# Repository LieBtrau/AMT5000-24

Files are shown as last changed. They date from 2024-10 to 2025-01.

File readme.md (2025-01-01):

# AMT5000-24
5W AM-transmitter for the 13.56MHz ISM-band

# Design choice
* DfM (Design for Manufacturability)
  * Use of COTS components
  * Use of standard PCB manufacturing techniques, no coil winding
  * Use of standard assembly techniques, preferably SMT
  * Ease of patching : SOIC instead of TSSOP
* Frequency : 13.56 MHz
  * ISM-band
  * Falls within SW-broadcast band, so AM-radios can be used
  * Antenna-length for a dipole is reasonable
  * [Carrier current](https://en.wikipedia.org/wiki/Carrier_current) is possible.  The mains power impedance isn't too low at this frequency.
  * 13.56MHz Class-E power amplifier designs is not uncommon
* Output power : 5W
  * remains within QRP limits

# Block diagram
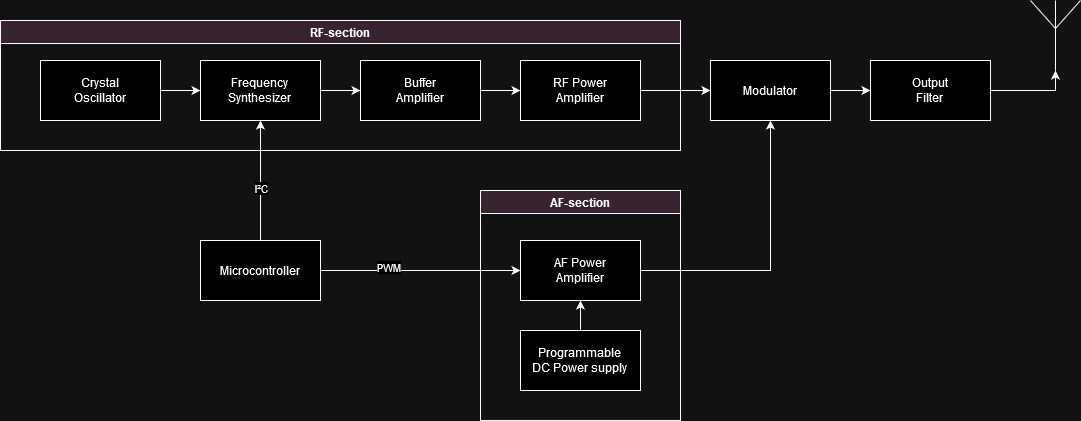
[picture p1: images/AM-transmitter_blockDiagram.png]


High-level AM-generator block diagram

## RF-section (Radio-frequency)
* [Crystal Oscillator & frequency synthesizer](./oscillator.md)
* [Buffer amplifier & RF-power amplifier](./rf-amp.ipynb)

## AF-section (Audio-frequency)
* Audio PWM-modulator using H-bridge IC (as on TR6000) : CSD97395Q4M
* [PWM-generator by ESP32 output](https://docs.espressif.com/projects/esp-iot-solution/en/latest/audio/pwm_audio.html)

## Modulator
Modulation happens by the output of the PWM-generator being used as power supply for the RF-power amplifier.

## Output filter
The output filter suppresses the harmonics of the switching frequency of the RF-power amplifier.

# Implementation
Instead of building a complete transmitter at once.  Prototyping will be done in stages.  The sections mentioned above will be designed as 50x50mm PCBs.  These will be tested separately and then combined onto a double sided 100x100mm FR4.  This allows us to:
* Test the sections separately and in combination with each other.
* A cheap double sided FR4 PCB can be used as a carrier for the sections.  This allows us to test the sections in combination with each other.
* Use the cheap PCB manufacturing services, like JLCPCB.  The 6 layer 50x50mm PCBs are only $2/5pcs.
* JST-PH will be used as connectors between the sections.
  * JST-PH for power
  * JST-PH for signals

The disadvantage is that the sections will be connected by wires, but we can use u.fl coax cables for signals.  All components should be SMD, not through hole, because of the carrier PCB.

# Why AM and not FM?
* Higher field strengths are allowed
* Receiver bandwidths are narrower (lower noise floor)
* AM is superior to FM under weak-signal conditions
* AM-band has more usable channels than FM
* construction is less critical because frequencies are low.
* only simple test equipment is needed

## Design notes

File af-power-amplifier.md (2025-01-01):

# Amplifier
There are three options to supply audio to the amplifier:
* Analog
  * Might suffer from noise, ground loops
  * Very versatile.  Allows to connect any audio source.
  * Simple software implementation, maybe even no software implementation at all.
* PWM
  * Fully digital signal path
  * CPU intensive, limited resolution and sampling rate
* I²S
  * Fully digital signal path
  * Less CPU intensive, higher resolution and sampling rate
  * An MCU with I²S output is needed

After much consideration, the analog input is chosen.

## Analog input
An alternative to generating audio by PWM is using a single ended class D amplifier with analog audio input.
Class-D amplifiers are much more efficient than class-AB amplifiers (e.g. the obsolete TDA2003).  The downside is that they're more complex.

### MPS options
The MP7740 and MP7741 are such devices.  They're not available on JLCPCB.
Their minimum input voltage is 9.5V, which is already quite high.  We might want to test the circuit with lower supply voltages to avoid burning the amplifier.

### TI options
[SLAA701A LC Filter Design](https://www.ti.com/lit/an/slaa701a/slaa701a.pdf) explains the difference between the BD-modulator and the AD-modulator.  Both modulators have a positive and Aan inverted output.  The difference is only in the inverted output.  For our application we can ignore the difference when using only the positive output.

Most recent class-D amplifiers use the BD-modulator.  The TPA3138D2 is such an amplifier.  It can be used as single ended, but TI [doesn't really recommend it](https://e2e.ti.com/support/audio-group/audio/f/audio-forum/927759/tpa3138d2-using-btl-amplifier-for-se-outputs-for-cost-savings). 
* TPA3118D2 (older) -> TPA3128D2 (upgrade): 2x 30W
    * JLCPCB

The following older class-D amplifiers use the AD-modulator:
* TPA3120D2
* TPA3121D2 (available on JLCPCB)
* TPA3123D2
* TPA3124D2 (compatible with the TPA3121D2, only a small difference in the mute control)

## PWM input
A fully digital signal path is used.  The ESP32 generates the PWM signal using the [PWM-audio component](https://docs.espressif.com/projects/esp-iot-solution/en/latest/audio/pwm_audio.html).  The PWM signal is fed to a half-bridge IC, which drives the speaker.

### Audio bandwidth
The minimum audio bandwidth for AM is around 3kHz.  The Qodosen DX-286 has a configurable audio bandwidth of 3kHz, 4kHz, 6kHz or even 8kHz.
So the minimum audio sampling rate should be at least 16kHz.

### PWM frequency & resolution
[PWM Distortion Analysis](http://www.openmusiclabs.com/learning/digital/pwm-dac/pwm-distortion-analysis/).  Key takeaways are :
* PWM is multiplication of your audio signal with a square wave at the PWM frequency
* Harmonics of the PWM frequency are generated
* Harmonics of the audio frequency are generated as well, because the audio signal isn't continuous, but a series of samples, sampled at the PWM frequency.
* Phase correct PWM has less (around 25dB) distortion than fast PWM
* PWM frequency should be at least 7 to 10 times the audio frequency

The ESP32 audio component only supports up to 48kHz PWM frequency, which is only three times the sampling frequency.

### Half-bridge IC
[CSD97395Q4M](https://www.ti.com/lit/ds/symlink/csd97395q4m.pdf)
* 60A peak current.  It's available on JLCPCB.
* The minimum ON-time is 40ns.
* €1.80 is quite expensive, but that's about the cheapest you can get for a half-bridge IC.

### Reconstruction filter


The PWM signal is fed to a low-pass filter to remove the PWM frequency and its harmonics.  The filter is a 2nd order Butterworth filter with a cutoff frequency of 6kHz, designed by [Markimicrowave](https://markimicrowave.com/technical-resources/tools/lc-filter-design-tool/).  The filter is designed for a 1ohm load impedance.
* L = 39µH → L = Wuerth 744776139 (lowest loss at 13.56MHz)
* C = 39µF → 4x 10µF, 1210 package

## I2S input
* TAS2770
  * minimum sampling rate is 44.1kHz.  48kHz is supported.
  * 20W output power
* TAS2505 has a class-D amplifier with I²S input. 
  * only 2W output power, so an extra half-bridge IC is needed.
  * Support for 8kHz to 96kHz sampling rates
  * available on JLCPCB (€1.50)
  * also has an analog input
  * the output pins don't seem to be perfectly differential according to the screenshots in the TI forum.
  * only 2W output power
* MAX98357A has a class-D amplifier with I²S input.  It's available on JLCPCB.
  * much more expensive than the TAS2505
  * simpler to use than the TAS2505
* PCM5242RHBR
  * used on Rapsberry Pi HATs
  * €9 @ JLCPCB (expensive!)

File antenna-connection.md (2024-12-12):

# RF-connector
* BNC : bulky, but easy to connect
* SMA : smaller but it takes some time to connect.  No visible check if it's connected properly.  You have to turn it to check it.
* U.FL : too small.  A cable assembly to a panel mount connector would be needed.  That introduces loss and extra cost.
* **MMCX** : a good compromise between BNC and SMA.  It's small and easy to connect.  It's also available in a panel mount version.  Popular in the drone industry.

# Protection
## Over-voltage
Over-voltage protection should be low capacitance but high voltage.  A GDT (gas discharge tube) seems like the only option here.

## Static discharge
The filter section of the class-E amplifier is isolated from ground.  To avoid building up a static charge, the filter section should be connected to ground.  This can be done with a 1M resistor.

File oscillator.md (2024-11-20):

# Oscillator
A crystal could be used, but we won't get better than 10ppm, let's use a TCXO instead.

## Requirements
* 25MHz or 27MHz
* sine wave output
* 3.3V supply
* Less than €2/pce
* frequency tolerance < 2ppm

## Part selection
SX2T25.000B010J020S

# Frequency synthesizer
The ESP32 can generate waveforms at 40MHz and much lower frequencies using the LEDC-peripheral, but the frequency resolution is very limited.  A PLL is required.  The Si5351A will be used:
* cheap
* popular in open-source projects, open-source code is available
* requires external crystal or clock

## Part selection
* Skyworks SI5351A-B-GTR, JLCPCB C504891
* MS5351M : less phase noise, but it's a clone.

# References
[QRP Labs Si5351A Synthesiser Module, PCB Rev 6](https://www.qrp-labs.com/images/synth/synth_assembly6.pdf)

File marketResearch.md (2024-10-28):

# Hobby circuits
* [How to Build an AM Radio Transmitter](https://www.circuitbasics.com/amplitude-modulated-transmitters/)
  * Colpitts oscillator in final stage.  Audio modulates the oscillator.
* [Build an AM Transmitter for Use with Antique Radios](https://www.nutsvolts.com/magazine/article/build-an-am-transmitter-for-use-with-antique-radios)
  * All linear circuits, no switching going on here.
* [M0DAD The Poppet](http://www.geocities.ws/raiu_harrison/mwa/tech/circuits/poppet.html)
  * Class-C amplifier
* [A simple AM modulator](https://www.giangrandi.org/electronics/am-mod/am-mod.shtml)
  * Class-C amplifier
* [FAT5 AM Transmitter](https://www.s9plus.com/index.html)
  * AM-transmitter in modules : Class E RF-amp, modulator (linear or PWM), oscillator

# Transmitter evaluation
## AM88
* Described in : "Build Your Own Low-Power Transmitters: Projects for the Electronics Experimenter by Rudolf F. Graf", §5. PLL Synthesized AM Transmitter for 530-1710 kHz
* 12VDC power supply
* AGC circuit
* PLL circuit could be replaced by MCU
* Chebychev output for filtering 2nd harmonic.  3 filters needed for 150kHz-1.8MHz range.

## DT6000
* [improved transmitter over AMT3000 and AMT5000](https://github.com/TransmitterPlans/DT6000-Transmitter-Files-)
  * [SSTRAN AMT-3000 am transmitter](http://www.radiomanual.info/schemi/Surplus_Radioamateur/SStran_AMT-3000_user.pdf)
  * [SSTRAN AMT-5000 ](https://github.com/TransmitterPlans/DT6000-Transmitter-Files-/blob/main/340473333-AMT5000Manual-R1-20110918-1106PM.pdf)
* Schematic is hard to read.
* includes antenna building info in appendix
* Uses AMT3000 audio / RF sections 
* 100mW
* AD9833 : DDS square wave generator
* ATMega328 control

## Wenzel
* [AM-transmitter](https://techlib.com/electronics/amxmit.htm)
* Low Power
* Also contains antenna tuning info
* LPAM handbook (includes antenna building info)

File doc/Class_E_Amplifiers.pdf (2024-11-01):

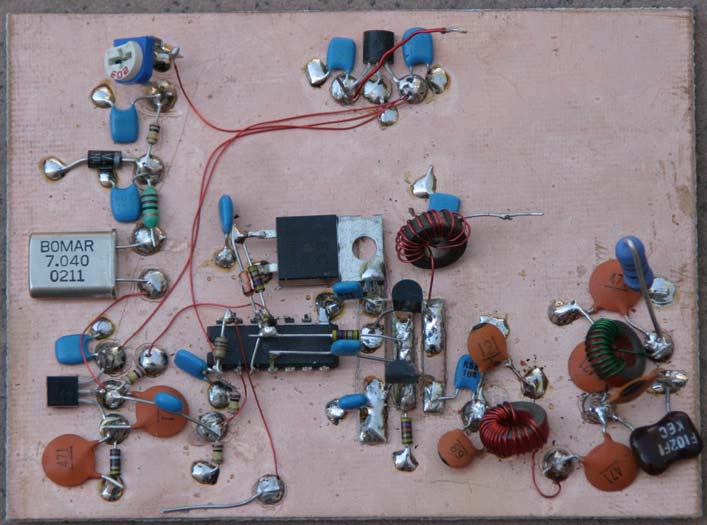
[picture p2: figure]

April-04 | N7VE / Ozarkc Copyright 1994, All rights reserved | on Class E Presentation

# Class E Amplifiers

## Part 1: Class E Basics

## Dan Tayloe, N7VE

## 5w Class E 40m Prototype

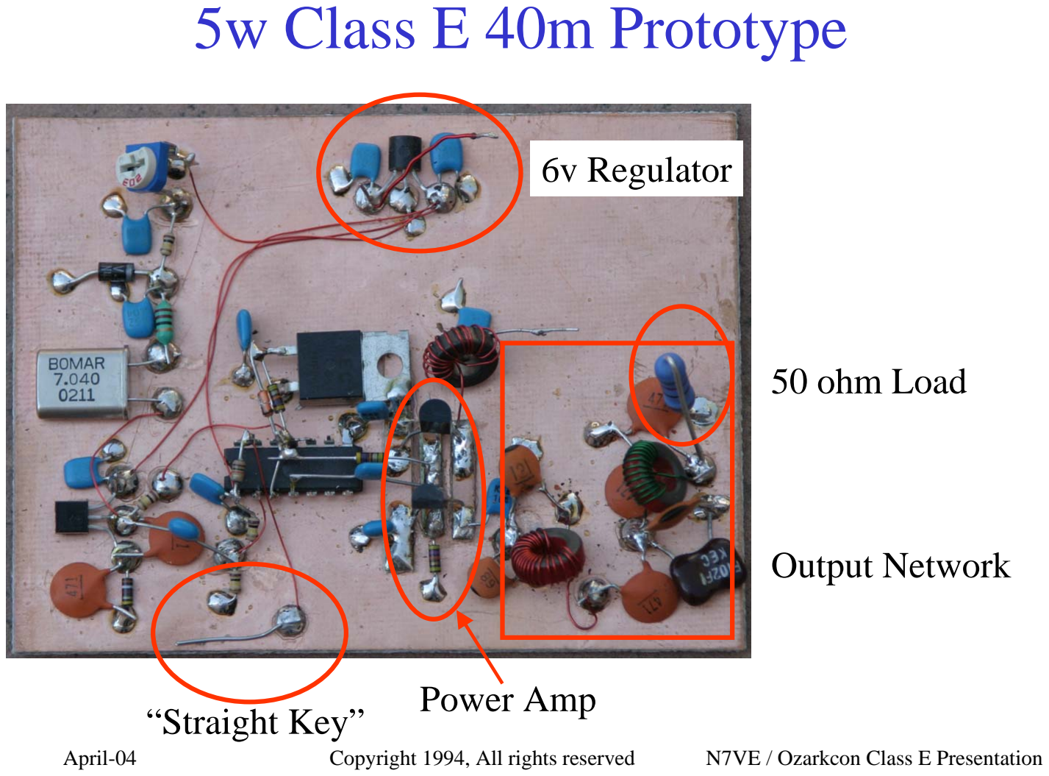
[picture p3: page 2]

April-04 | N7VE / Ozarkc Copyright 1994, All rights reserved | on Class E Presentation

Power Amp

6v Regulator

Output Network

50 ohm Load

“Straight Key”

April-04 | N7VE / Ozarkc Copyright 1994, All rights reserved | on Class E Presentation

# Why Class E?

Class C final, 2w
40 to 45% efficient, ~ 370 to 410 ma*

Class E final, 2w
88% efficient, ~ 190 ma*

Almost 50% less TX current required… Very battery friendly!

* Does not include PA driver. Class E can require very little driver power!

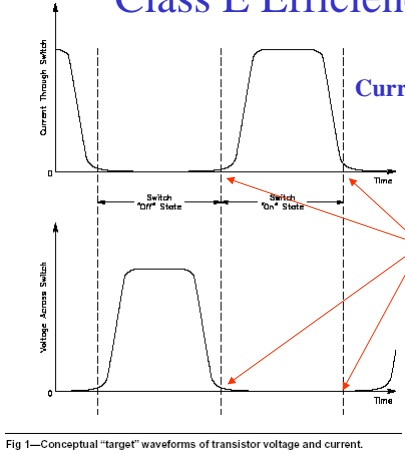
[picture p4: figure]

April-04 | N7VE / Ozarkc Copyright 1994, All rights reserved | on Class E Presentation

# Class E Efficiency Secret

Voltage vs. time

Current vs. time

Taken from QEX Jan/Feb 2001

Switch at low current,
Low voltage points
~Zero power at switch!

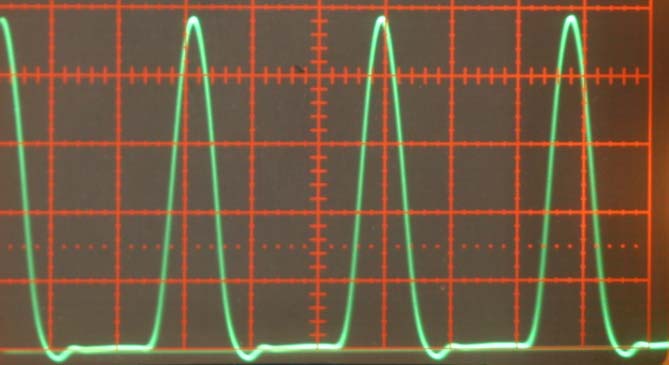
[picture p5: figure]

April-04 | N7VE / Ozarkc Copyright 1994, All rights reserved | on Class E Presentation

# Class E Drain Voltage Waveform

Scale 10v/division
~ 48v at peaks for 5 w, ~40v for 2w
For comparison, Class C devices run only 24v peaks

## Class E Design Spread Sheet, 7 MHz

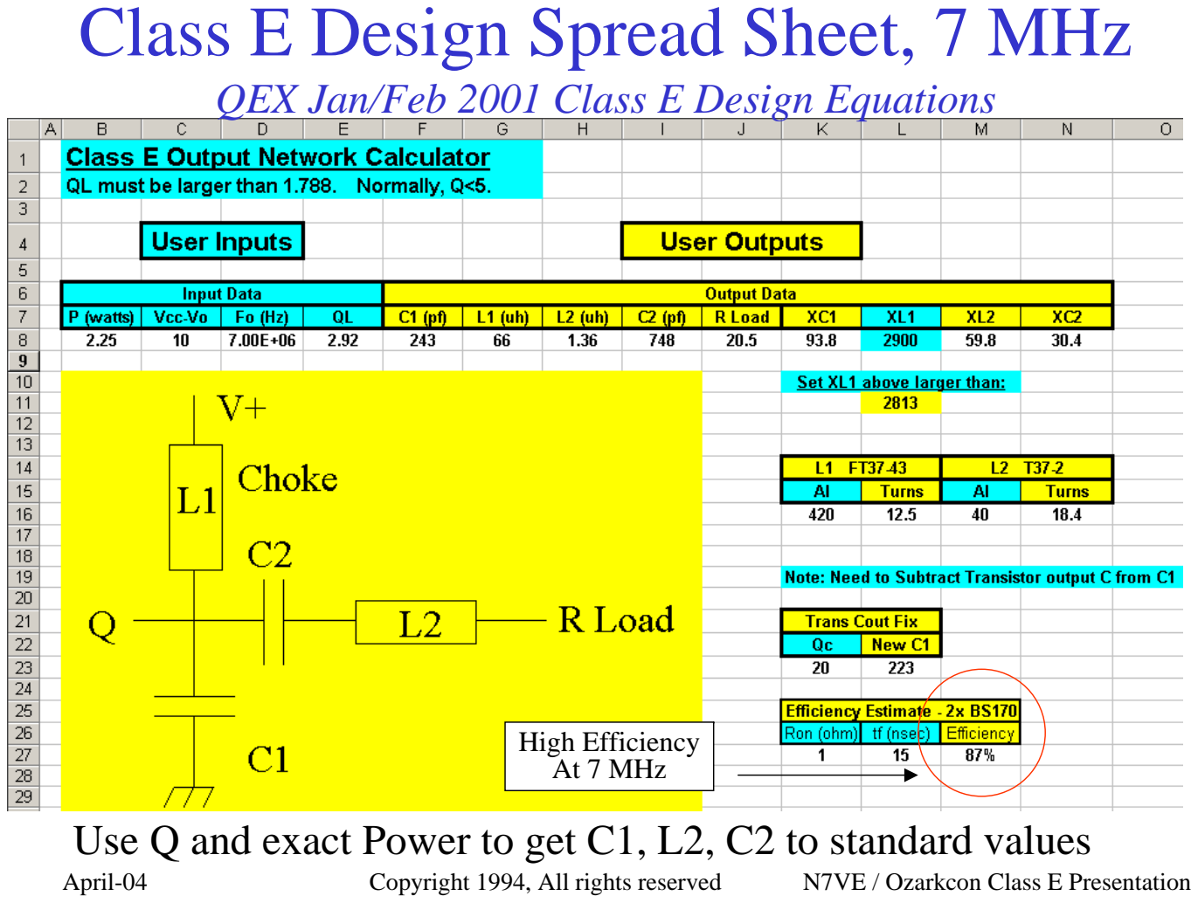
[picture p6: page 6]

April-04 | N7VE / Ozarkc Copyright 1994, All rights reserved | on Class E Presentation

QEX Jan/Feb 2001 Class E Design Equations

High Efficiency
At 7 MHz
Use Q and exact Power to get C1, L2, C2 to standard values

## Class E Design Spread Sheet, 14 MHz

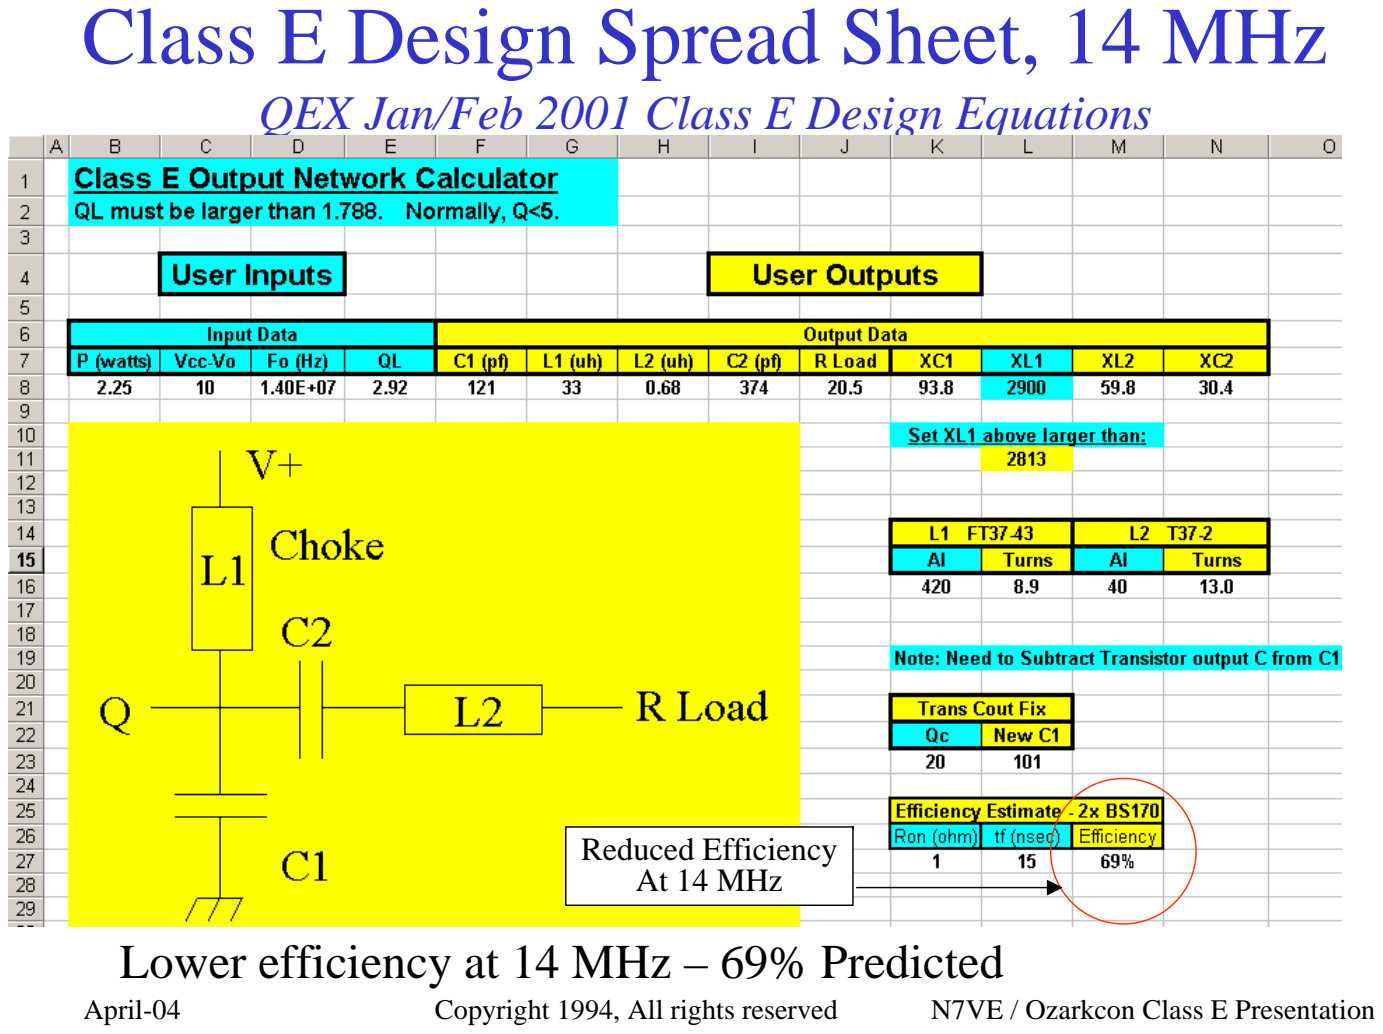
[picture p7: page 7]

April-04 | N7VE / Ozarkc Copyright 1994, All rights reserved | on Class E Presentation

QEX Jan/Feb 2001 Class E Design Equations

Reduced Efficiency
At 14 MHz
Lower efficiency at 14 MHz – 69% Predicted

April-04 | N7VE / Ozarkc Copyright 1994, All rights reserved | on Class E Presentation

# Class E Design Spread Sheet

Excel spread sheet equations…

C1 (pf) = (1e12/(J8*34.2219*D8))*(0.99866 + 0.91424/(E8) -1.03175/(E8*E8)) + 0.6/(2*2*3.14*3.14*D8*D8*G8/1000000)

C2 (pf) = (1e12/(J8*2*3.14*D8))*(1/(E8-0.104823)) *(1.00121 + 1.01468/(E8 - 1.7879)) -0.2/(2*2*3.14*3.14*D8*D8*G8/1000000)

L1 (uH) = 1000000*L8/(2*3.14*D8)

L2 (uH) = 1000000*J8*E8/(2*3.14*D8)

Rload = (C8*C8/B8)*0.576801*(1.001245 - 0.451759/E8 - 0.402444/(E8*E8))

XL1 >= 30*K8

Efficiency = J8/(J8+1.365*K27) -0.01
- (1+ 0.82/E8)* (1+ 0.82/E8)*4*PI()*PI()*D8*D8*L27*L27*1e-18/12

April-04 | N7VE / Ozarkc Copyright 1994, All rights reserved | on Class E Presentation

# Class E Amplifiers

## Part 2: No Tune, Goof Proof Class E Amps

## Dan Tayloe, N7VE

April-04 | N7VE / Ozarkc Copyright 1994, All rights reserved | on Class E Presentation

# Problems with Class E QRP Amps

- “Tuning” required to get good efficiency
- Poor “out of the box” power and efficency
- Typical to “tweak” output network coils for best power/efficiency
- Class E finals fail when presented with low impedance loads
- Low impedance loads cause PA to draw too much current and burn up
- Inexpensive QRP Class E final rated to only 60v (2N7000)
- Typical PA drain voltage operates in the 40 to 50v range w/ 12v supply
- Improper antenna mismatch can raise drain voltage, blow the PA
- 15v supply used with a 12v design could cause problems
- Class E Amps can be unstable into poorly matched loads
- Tends to “take off”
- Can lead to device failure

April-04 | N7VE / Ozarkc Copyright 1994, All rights reserved | on Class E Presentation

# Class E Tuning Problem

- Class E matching network typically presents a reactive load
- I.e., the Class E PA output impedance is not purely resistive
- Reactive characteristic key to Class E efficiency
- QRP Class E networks need loads in the 10 ohm to 50 ohm (5w to 1w) range
- Matching network normally needed to transform to 50 ohm load
- 1 watt 12v final is a design “sweet spot” – no matching needed
- L/C matching networks are typically used to transform driver impedance to 50 ohm load impedance.
- This approach does not work well with a reactive drive source!
- Leads to frequency specific matching network
- Variations in driver network and matching network elements force the need for “tuning” of the matching networks

# No Tune Class E

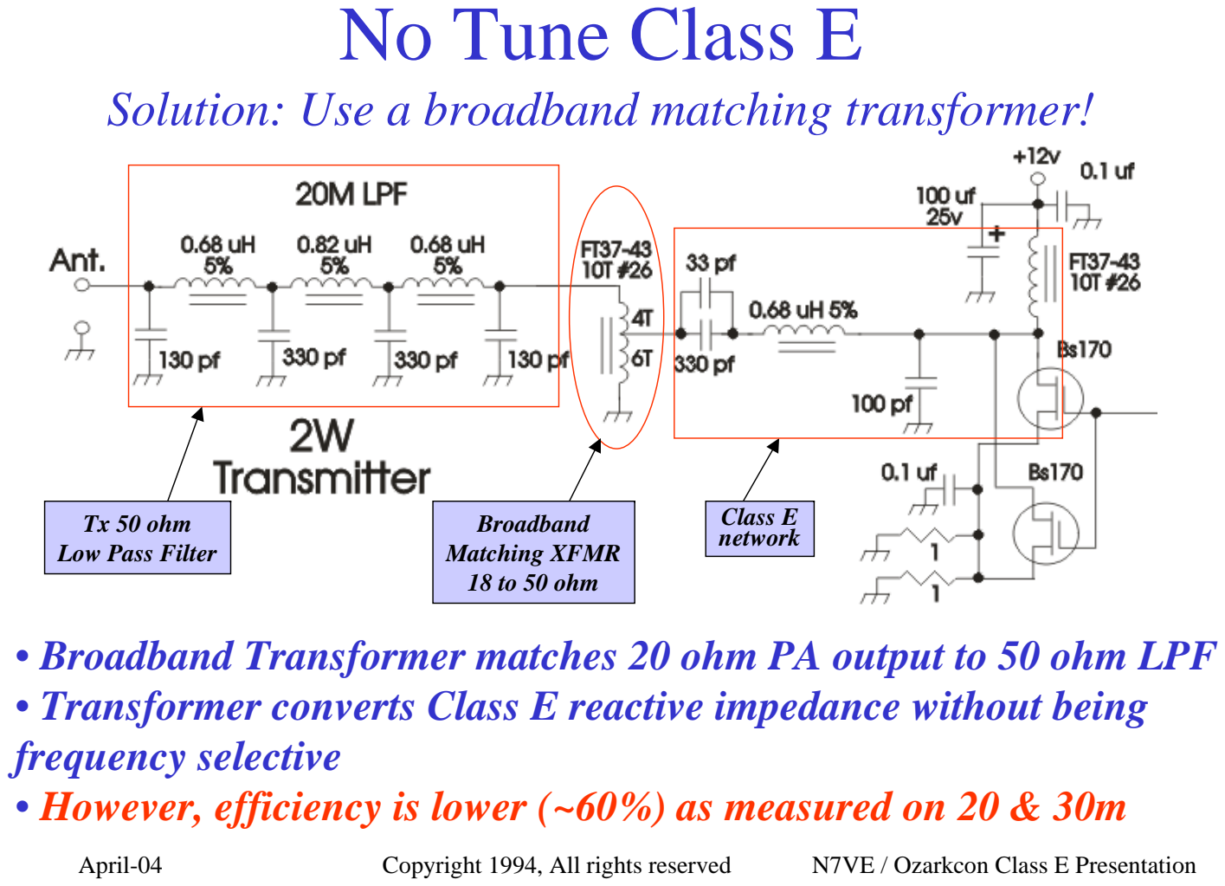
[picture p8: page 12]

April-04 | N7VE / Ozarkc Copyright 1994, All rights reserved | on Class E Presentation

Solution: Use a broadband matching transformer!

- Broadband Transformer matches 20 ohm PA output to 50 ohm LPF
- Transformer converts Class E reactive impedance without being frequency selective
- However, efficiency is lower (~60%) as measured on 20 & 30m

Tx 50 ohm
Low Pass Filter

Broadband
Matching XFMR

### 18 to 50 ohm

Class E
network

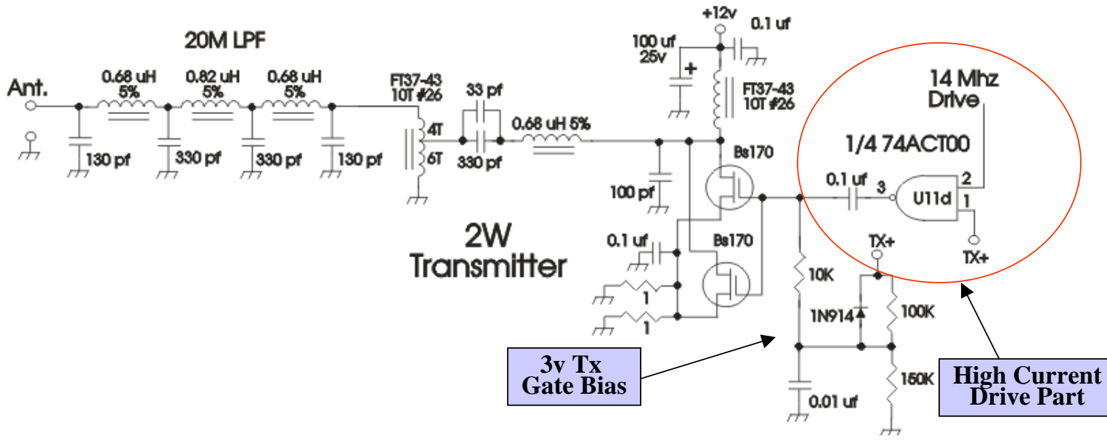
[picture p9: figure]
Gate Bias; High Current Drive Part

April-04 | N7VE / Ozarkc Copyright 1994, All rights reserved | on Class E Presentation

# Class E Load Instability

Solution: Use a lower impedance gate driver!

- AC family has 24 ma of drive vs 8 ma for HC family
- Higher current drive = lower drive source impedance
- 3x lower source impedance reduces tendency to “flight” with mismatched load
- PA gate biased on TX to 3v to help MOSFET turn on harder

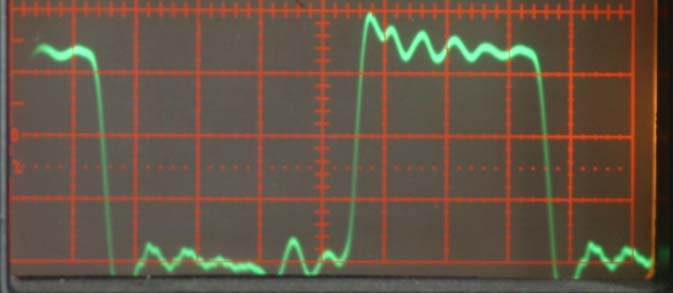
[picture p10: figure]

April-04 | N7VE / Ozarkc Copyright 1994, All rights reserved | on Class E Presentation

# Class E Driver – 74ACT00

Scale: Vertical 2v/div, Horizontal 20 nsec/div 6 to 8v at peaks
Very fast rise+fall times: ~10 nsec total

74ACT00 has 24 ma of drive vs. only

8 ma for
the more common 74HCT00 parts

# Class E Voltage Limitations

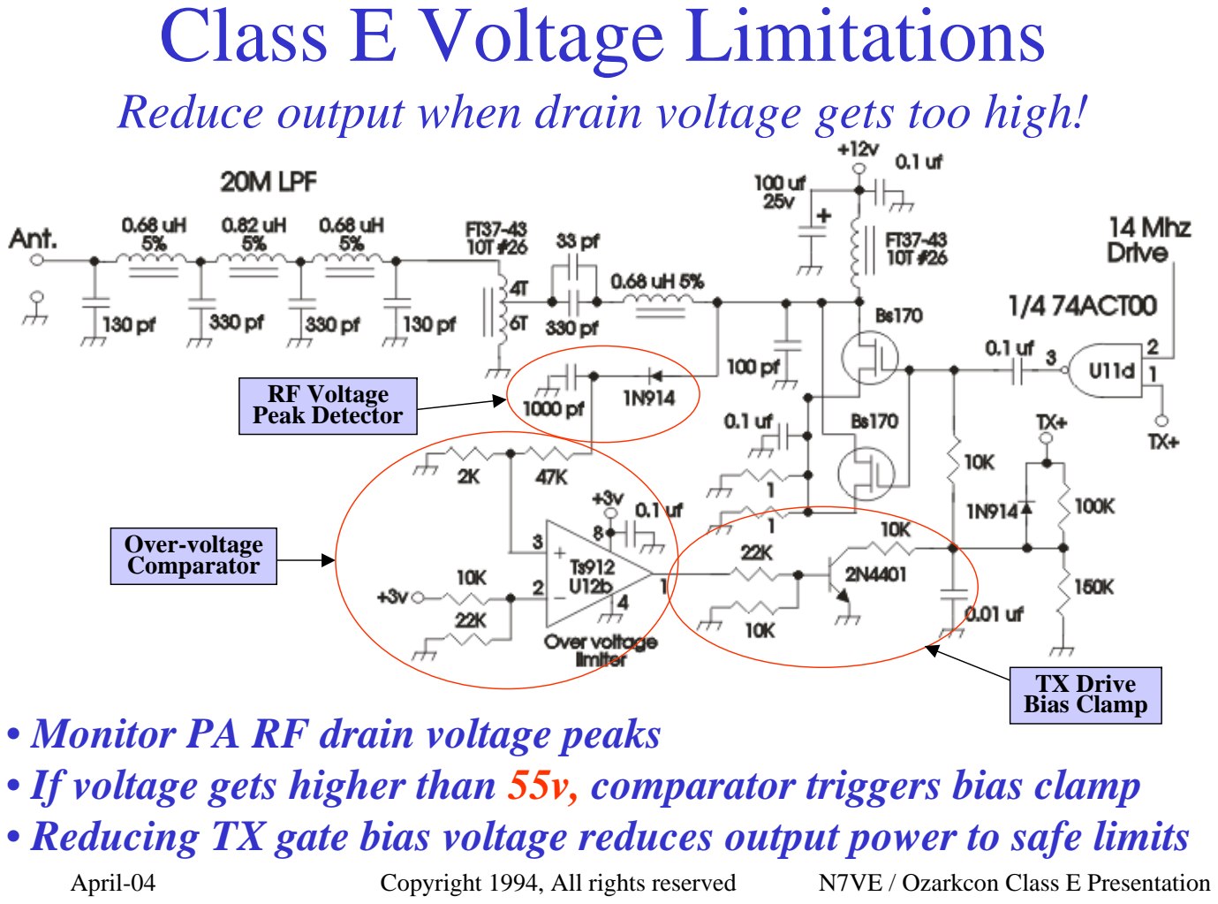
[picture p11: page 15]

April-04 | N7VE / Ozarkc Copyright 1994, All rights reserved | on Class E Presentation

Reduce output when drain voltage gets too high!

- Monitor PA RF drain voltage peaks
- If voltage gets higher than 55v, comparator triggers bias clamp
- Reducing TX gate bias voltage reduces output power to safe limits

Over-voltage Comparator

RF Voltage Peak Detector

TX Drive
Bias Clamp

# Class E Low Load Limitations

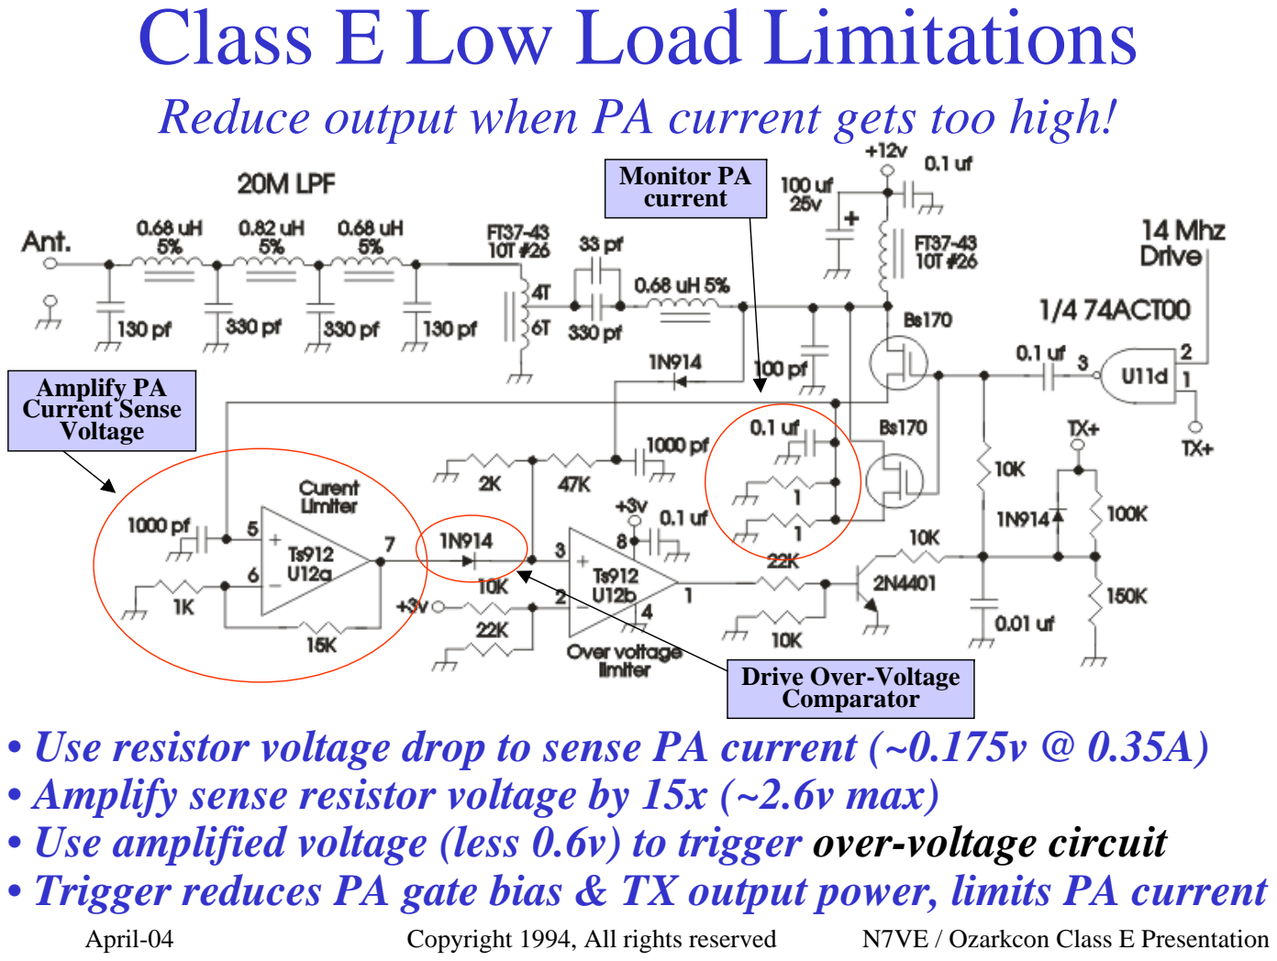
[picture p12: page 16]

April-04 | N7VE / Ozarkc Copyright 1994, All rights reserved | on Class E Presentation

Reduce output when PA current gets too high!

- Use resistor voltage drop to sense PA current (~0.175v @ 0.35A)
- Amplify sense resistor voltage by 15x (~2.6v max)
- Use amplified voltage (less 0.6v) to trigger over-voltage circuit
- Trigger reduces PA gate bias & TX output power, limits PA current

Monitor PA
current

Amplify PA Current Sense
Voltage

Drive Over-Voltage Comparator

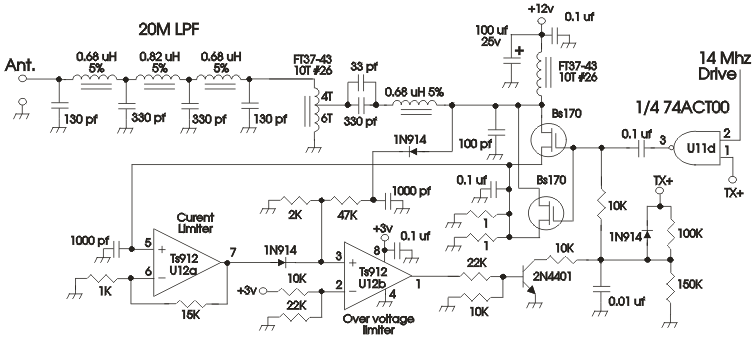
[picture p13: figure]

April-04 | N7VE / Ozarkc Copyright 1994, All rights reserved | on Class E Presentation

## No Tune, Goof Proof, Class E Tx

- High impedance over-voltage protection
- Low impedance over-current protection
- “No Tune” Class E output

April-04 | N7VE / Ozarkc Copyright 1994, All rights reserved | on Class E Presentation

## Current Class E Limitations

- Efficiency of common QRP PA devices (2N7000, BS170) drops off at 14 MHz and above
- ~80 to 90% efficiency at 10 MHz and below
- ~70% efficiency at 14 MHz
- ~60 % efficiency using “no tune” approach shown here
- R/C freq response: Smaller Driver R = Higher Freq response
- Higher PA drive power can be used to get higher freq PA response
- Higher PA drive power hurts overall transmitter power saving
- Higher frequency devices available, but more expensive
- Example: STMicroelectronics PD57006s 900 MHz 5w FET, ~$12

April-04 | N7VE / Ozarkc Copyright 1994, All rights reserved | on Class E Presentation

## Current Class E Limitations, cont

- Class E operates at a fixed power set by Class E output network
- Variable power best done by changing supply voltage
- May be able to reduce power from preset maximum by lowering TX gate drive bias, but at reduced TX efficiency.

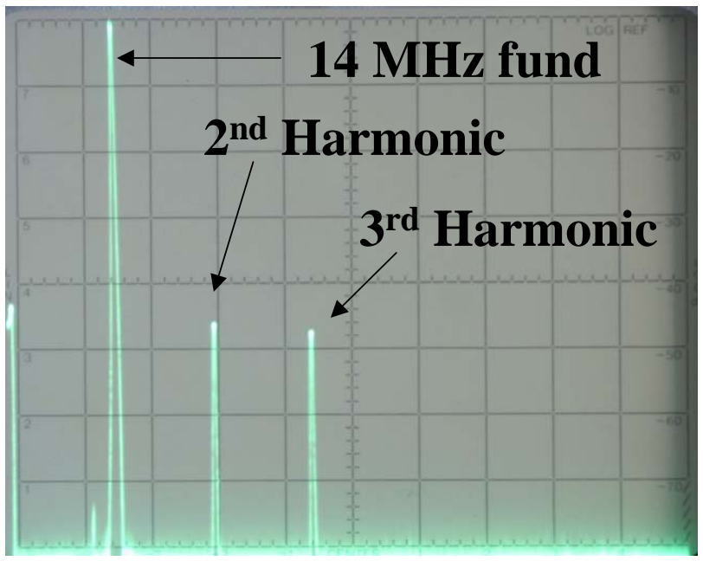
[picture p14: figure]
14 MHz fund 2nd Harmonic; 3rd Harmonic

April-04 | N7VE / Ozarkc Copyright 1994, All rights reserved | on Class E Presentation

# Transmitter Spectrum

Scale 10 db/division – legal limit 30 db down 2nd Harmonic ~45 db down
3rd Harmonic ~47 db down
All other more than 70 db down

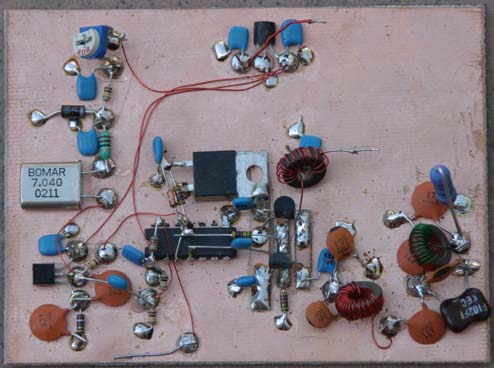
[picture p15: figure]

April-04 | N7VE / Ozarkc Copyright 1994, All rights reserved | on Class E Presentation

# Class E Amplifiers

## Part 3: Good & Bad QRP Class E Devices

Or

## “Bigger is not Better”

## Dan Tayloe, N7VE

April-04 | N7VE / Ozarkc Copyright 1994, All rights reserved | on Class E Presentation

# Why the IRF510 Makes a Good 5w Class C PA

## - IRF510 on/off time 70 nsec, good to 14 MHz - 40 to 45% efficiency typical using broadband, low pass TX output filters - 5w output requires 11.1w input power

– 6.1w of heat produced!
– 33w IRF510 can take the heat
if proper heat sink is used

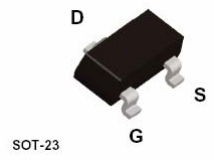
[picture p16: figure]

April-04 | N7VE / Ozarkc Copyright 1994, All rights reserved | on Class E Presentation

# Why the 2N7000 makes a good QRP Class E final

# and the IRF510 does not

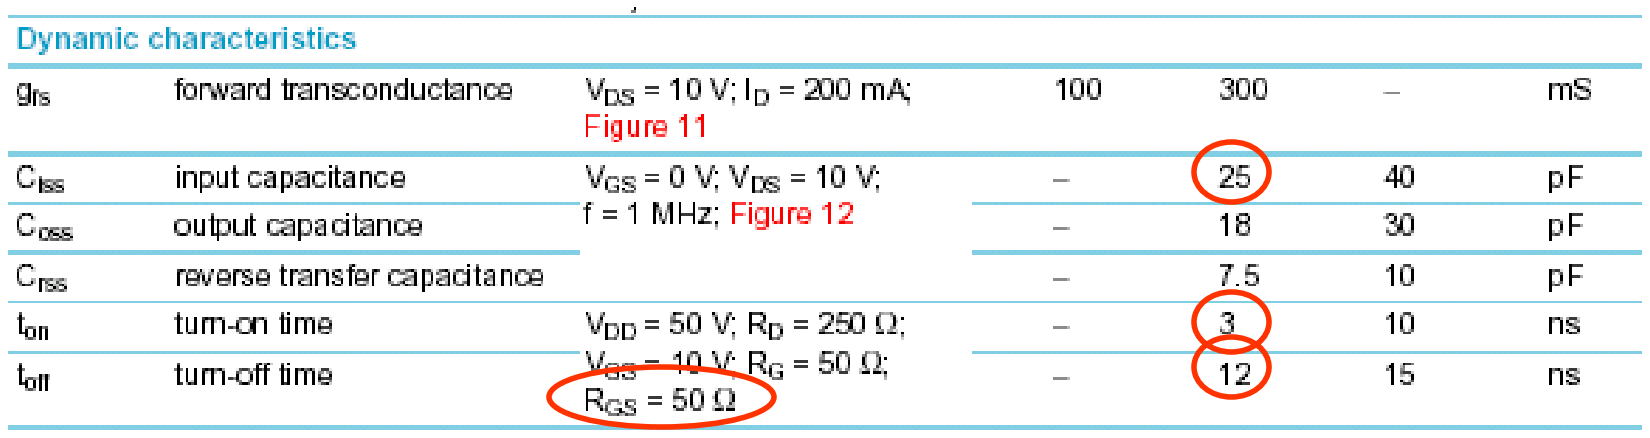
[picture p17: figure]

April-04 | N7VE / Ozarkc Copyright 1994, All rights reserved | on Class E Presentation

# Good FET – 2N7000, 0.3 to 0.6w

Low input C: 25 pf typical – Low input drive drive!
Fast Turn on/off time: 3+12 nsec = 15 nsec

For class E, need On/Off to be 30% of ½ RF cycle (QEX 1/01)
- Gives maximum limit of 10 MHz for full efficiency
- Can be used at 14 MHz at reduced efficiency
- Measured 80-90% at 7 & 10 MHz, 70% at 14 MHz

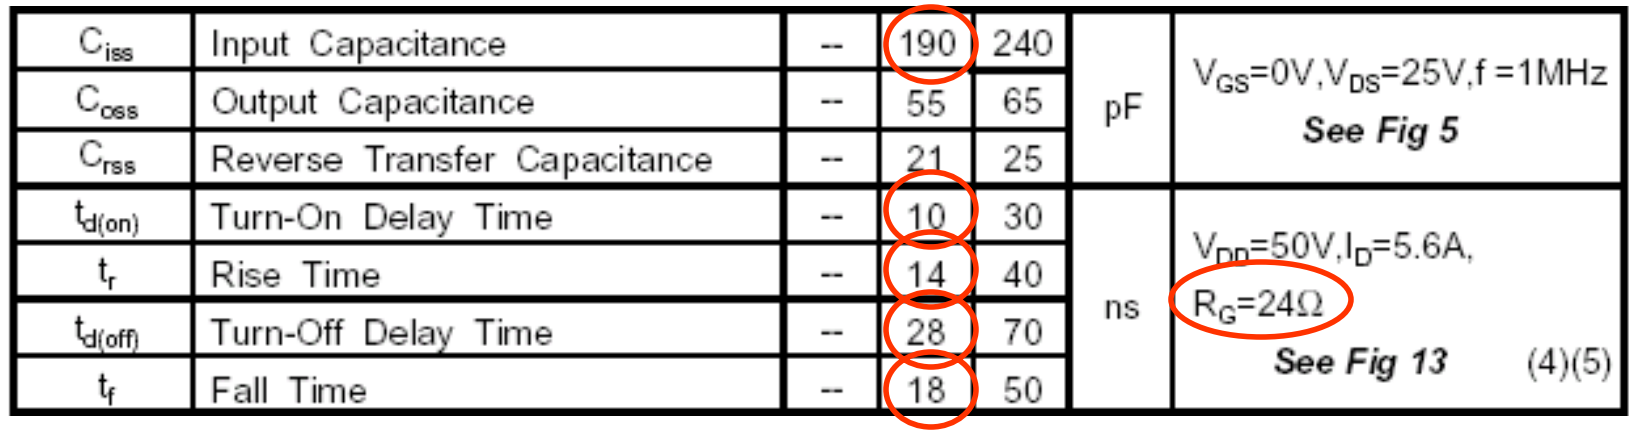
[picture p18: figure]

April-04 | N7VE / Ozarkc Copyright 1994, All rights reserved | on Class E Presentation

# Difficult FET – IRF510, 33w

Higher input C: 190 pf typical – Higher input drive needed!
- Specs use 24 ohm source here vs. 50 ohm source for 2N7000
Slower Turn on/off time: 10+14+28+18 nsec = 70 nsec For class E, need On/Off to be 30% of ½ RF cycle
- Gives maximum limit of 2 MHz for full efficiency
- Can speed up by using a lower impedance drive source.
- Slam it on, slam it off! – more drive power needed. Double driver power hit: High input C & Slow switching time

April-04 | N7VE / Ozarkc Copyright 1994, All rights reserved | on Class E Presentation

## Class E Driver Requirements IRF510 vs. 2N7000

- IRF510, 190 pf input gate C; 2N7000, 25 pf
– Drive power factor of 7.6x
- IRF510, 25 ohm source; 2n7000, 50 ohm source
– Drive power factor of 2x
- IRF510, 70 nsec turn on/off; 2n7000, 15 nsec
– Need 4.67x lower drive impedance to get same speed
- IRF510 requires 5 ohm driver impedance for 15 nsec on/off
Total drive difference: IRF510 needs 71x more drive power than a single 2N7000
~ 0.6w drive for class E IRF511 vs. 17mW for a pair of 2N7000s
IRF510: Good 100w Class E amp, poor 5w amp!

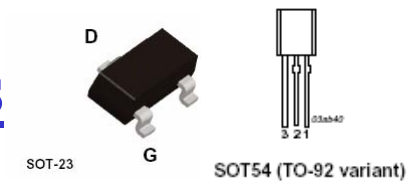
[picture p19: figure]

April-04 | N7VE / Ozarkc Copyright 1994, All rights reserved | on Class E Presentation
- Class E saves ~ 50% on TX DC input power to PA
– Low drive power (17 mW vs. 0.6w) saves additional power
- Class C requires large TO220 PA transistors
- Class E needs only tiny T092/SOT23 300mw/600mw packages
- $0.14 for a new pair of Class E QRP finals!
- Low wasted TX pwr (Heat

)
– For 5w output, 0.5 to 1w heat (class E) vs. 5 to 6w heat! – Conserves battery life (smaller battery?)
– Reduces VFO drift

# Conclusions

April-04 | N7VE / Ozarkc Copyright 1994, All rights reserved | on Class E Presentation

# Class E Summary

## - Class E can give up to 88% efficiency

– But require tuning to get proper power output
- Protection circuitry available for Class E finals
– Protects against antenna open/short/mismatch problems
- “No Tune” Class E works, but ~60% efficiently
- Bigger is not better for Class E finals
– High power MOSFETs (such as the IRF511) require high drive power (71x!), reducing overall rig efficiency.

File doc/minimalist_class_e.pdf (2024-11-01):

## Search for the Minimalist QRP Class E Amplifier Filter Typology

Scott Howard (KD9PDP)

## Quick Summary: Do this!

Use a Pi-networks with second-harmonic notch filter, as seen in Figure 1 and design equations are below and shown in Section 2.1.2. Alternatively, you can use a T-network with a second-harmonic notch filter with similar results. You can to trade off power and efficiency a little bit as you see fit: see Table 1 for a

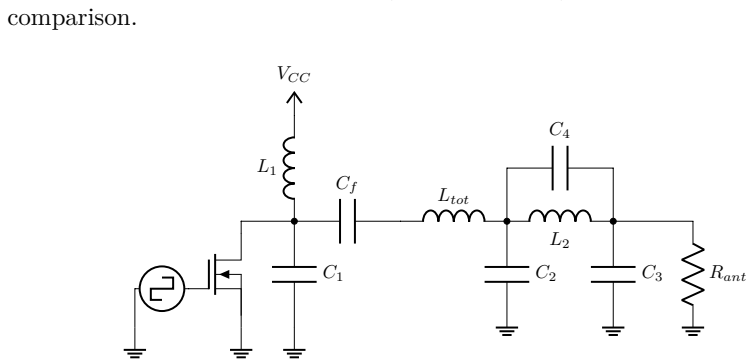
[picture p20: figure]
comparison.; VCC; Ltot; Rant

Figure 1: Class E amplifier with pi-network with second harmonic notch

David Cripes (NM0S) was the first to promote this typology, and there is a great design spreadsheet based on it. The design equations presented here are a little different, provide more flexibility, and yield slightly higher efficiencies for the same output power (e.g., 89% vs 85% at 3 W output).

Design Procedure

This is a minimalist, easy version of Section 2.1.2.

This work is licensed under a Creative Commons “Attribution-ShareAlike 4.0 International” (https://creativecommons.org/licenses/by-sa/4.0/deed.en) license.

1

1. Pick a desired output power. You’ll be practically limited by thermal effects. Based on SPICE simulations, for VCC = 12 V with 3 parallel BS170 transistors, desired output power should be less than 4 W. Find the value for the apparent load resistance and the corresponding circuit Qs:

RL = 0.58

V

2
CC
Pout

Q = 3 + r
RL
5

− 1

2. Find all the component values:

C1 =

1
5.4466ωRL

L1 2.84RL
ω

Cf =

1
QωRL

Ltot = (Q + 1.1525)RL
ω

C2 =

(Q − 3)
ωRL

C3 =

3
50ω

L2 =

15Q
4ω

C4 =

1
15Qω

How did we get the simplified equations?

The simplification comes from taking the equations in Section 2.1.2 for a 50 Ω antenna, then setting Rv = 5 and solving the equations. It’s perfectly valid and rigorous to just set Rv = 5, there are no approximations made. Rv = 5 corresponds to choosing a Q ≈ 5 for all RL from 15 to 50 Ω. Since we’re free to choose any Q we want (granted we achieve the required harmonic suppression, which we do) it’s valid!

2

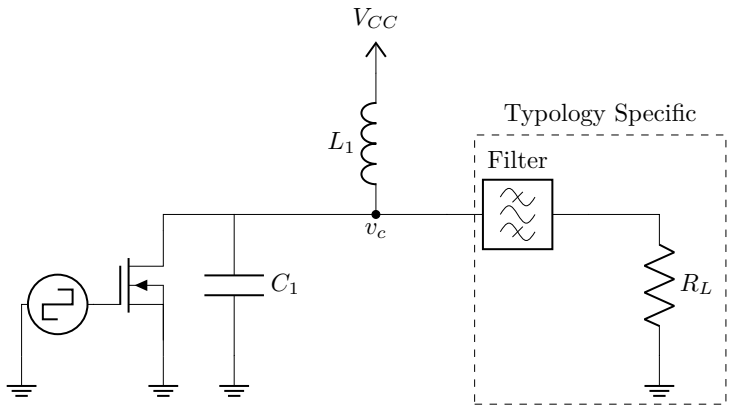
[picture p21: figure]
VCC; Filter; Typology Specific

Figure 2: Generic Class E Amplifier

## 1 Intro

Class E power amplifiers are popular for use in QRP transmitters because of they achieve high efficiency (> 90%) using relatively common and inexpensive components. While there’s a lot of info out there about Class E theory and design, there hasn’t been many comparative reviews of the different approaches to building a Class E amplifier. Understanding the approaches can better guide balancing complexity and performance, as well as make sure incompatible filters are not used. While tempting, adding on a filter you are comfortable with to the output of a Class E amplifier might be incompatible with the design typologies, so hopefully this analysis can help prevent those issues while also determining what is minimally required for a good QRP Class E design.
First, this paper will show a comparison of the different general typologies in Section 2. As a reference, a theoretically derivation of the standard design equations is given in Section 3. A companion paper looks at the QCX Class E design, a unique design that’s fundamentally different than the standard designs, but requires more components to achieve similar efficiency. It’s important to mention because QCX Class E is fundamentally incompatible with “standard” design typologies and filters.

## 2 Overview of Typologies

Nearly all amateur radio QRP Class E amplifiers look like Figure 2. Some square wave signal modulates the gate of a MOSFET. The drain is biased through an inductor L1 and connected to ground through C1. Gate modulation causes voltage modulation at the drain. Filters are used to extract the RF signal you would like to apply to your load resistor RL (i.e., your antenna).
The design choices therefore become:

3

- What value should I choose for L1?
- What value should I choose for C1?
- What filter should I use?

– How much filtering do I need to do? (The FCC requires that the average power of spurious emissions are at least 43 dB below the fundamental frequency. FCC 97.307d.)

– What complex impedance should the filter present? (required for high efficiency operation)

– Do I need my filter to do any impedance matching or impedance transformation on RL to transmit at a desired power level?

- Other typologies: There (literally) an infinite number of other types. However, DIY QRP transmitters tend to keep it simple. For example, amplifiers with shunt capacitors and shunt filters can work too.

There are several strategies to answer the above questions. These strategies can be broken down as follows:

- ‘‘Standard” Designs, the most common in QRP and homebrew devices. Mostly based on Nathan Sokal’s (WA1HQC) 2001 QEX article. A large RF choke is used for L1. The “standard” design equations are derived in Section 3 where we’ll find:

C1 =

1
5.4466ωRL

L1

2.84RL
ω

as a note, above shows a the results of a new derivation and approach for finding the limit for what to make L1. This design has the following filter requirements: infinite impedance at DC and all frequencies except the fundamental frequency. The filter should present a specific complex inductive load at the fundamental frequency. There are several approaches to developing appropriate filters that we will explore:

– A standard LC series bandpass filter.

– An LC bandpass filter in series with an L impedance matching low-pass filter to achieve higher output power.

– An LC bandpass filter placed in series with a Pi or T impedance matching low-pass filter. This achieves improved harmonic suppression and higher output power.

– An LC bandpass filter in series with a Pi or Timpedance matching low-pass filter that utilizes a notch filter to essentially eliminate the second harmonic spurious emission and achieving higher output power. This was first shown to be effective by David Cripe (NM0S) and described in his “Class E Power Amplifiers for QRP” paper.

4

- “QCX Class E.” This design is used in the QCX QRP transceiver¹ . The
QCX design equations are derived in the complimentary document:

L1 =

3πRLZ(2ω)
[2RL + 8Z(2ω)]ω

C1 =

1
L1(2ω)

2

Where Z(2ω) is the entirely real impedance at 2ω. This design has the following filter requirements: infinite impedance at DC, purely real (resis-tive) at the fundamental frequency, purely restive (or large) at the second harmonic, capacitive at all other harmonics. So far, only one filter typology has been used, seen in Figure 7.

The design equations for all the above are derived in the following sections. We can use those equations in SPICE models to simulate performance. Ngspice was used to evaluate each of the above typologies to compare what is needed for a minimal QRP transmitter, the results are presented in Table 1. Increased complexity filter yields both higher harmonic suppression and smaller inductors. The simplest amplifier typology to reach FCC requirements is a Pi-network, and both Pi- and T-networks are appropriate when combined with a second harmonic notch filter. The following sections explore all of this in more detail.

### 2.1 Standard/Traditional Class E

The standard Class E is given in Figure 3. A simple series LC bandpass filter performs both filtering and impedance matching (see Section 3 for derivations). However the filter must be very high (Q > 40) to reach the 43 dB of harmonic filtering required, and therefore is not seen in QRP transmitters. However, this model gives us the starting point to improve performance since it gives us the general things we we want: (a) a high impedance at all frequencies except our designed fundamental frequency ω (green line in Figure 3) and (b) some harmonic attenuation . We need 43 dB (red line in Figure 3), and since Class Es naturally have 5.7 dB harmonic suppression, our filter should at least suppress ≈ 37.3 dB (dotted red line) at the second harmonic (dashed green line).
The component parameters for a desired bandwidth (Qf =

f
∆f

) when the
load resistance is equal to the antenna resistance RL = Rant can be found using:

Cf =

1
QfRLω

Ltot =

RL
ω

(Qf + 1.1525)

Generally, R is the real resistance of the load seen at the MOSFET drain (i.e., the resistance RL after the LC transformers in the sections below).
Sokal has a famous QEX paper that addresses Class E amplifiers with finite Qs. Basically, if your impedance at harmonics is not infinity, your can’t have the ideal, theoretical 100% efficiency. An intersting note is that when the paper was written, QRP transmitters only needed 30 dB of harmonic suppression, so Q = 20 would work. The larger suppression requirements now require more complicated filters, which causes the equations to be a little bit different.

1https://qrp-labs.com

5

Spur. Rej./
Type | RL | Q | Max. L | # L | Notch | hPouti | η
Std. | 50 | 20 | 24 µH | 1 | 32 dB | 1.5 W | 94%
L-match | 10 | 20 | 5 µH | 1 | 40 dB | 4.0 W | 63%
L-match | 15 | 20 | 7 µH | 1 | 37 dB | 4.0 W | 80%
L-match | 20 | 20 | 10 µH | 1 | 37 dB | 3.3 W | 86%
L-match | 25 | 20 | 18 µH | 1 | 36 dB | 2.8 W | 89%
Pi-match | 10 | 5 | 1.4 µH | 2 | 49/70 dB | 4.1 W | 63%
Pi-match | 15 | 5 | 2.1 µH | 2 | 48/70 dB | 4.2 W | 81%
Pi-match | 20 | 5 | 2.8 µH | 2 | 48/70 dB | 3.5 W | 86%
Pi-match | 25 | 5 | 3.4 µH | 2 | 48/70 dB | 3.0 W | 89%
Pi-match | 50 | 5 | 6.9 µH | 2 | 49/70 dB | 1.6 W | 94%
T-match | 10 | 5 | 2.2 µH | 2 | 34/54 dB | 3.6 W | 83%
T-match | 15 | 5 | 3.2 µH | 2 | 36/56 dB | 2.8 W | 87%
T-match | 20 | 5 | 4.2 µH | 2 | 38/58 dB | 2.4 W | 89%
T-match | 25 | 5 | 5.1 µH | 2 | 39/59 dB | 2.1 W | 91%
T-match | 50 | 5 | 9.7 µH | 2 | 40/60 dB | 1.6 W | 94%
QCX | 50 | | 1.7 µH | 3+1 | 45 dB | 3.4 W | 85%
NM0S Notch | | | 1.1 µH | 2 | 57 dB | 3.0 W | 85%
NM0S Notch | | | 0.7 µH | 2 | 57 dB | 4.0 W | 75%

Table 1: ngSpice models of Class E amplifiers (using 3 parallel BS170 transistors). f = 7.1 MHz VCC = 12 V, Rant = 50 Ω. Max L is largest inductor value (excluding choke inductor) and “# L” is the number of inductors in the filter (QCX has a +1 because the feed inductor is also frequency dependent and acts as part of the filter). Spurious rejection is given without and with “notch” filters (see text). Q < 20 for required bandwidth.

6

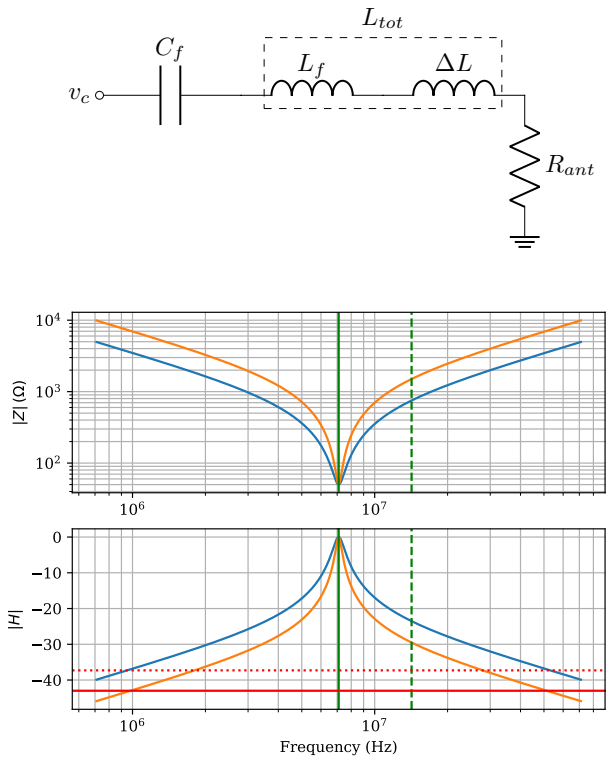
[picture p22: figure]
Rant; Ltot; 7 Frequency (Hz)

Figure 3: Traditional LC bandpass filter for a Class E Amplifier for Q = 10 (blue) and Q = 20 (orange). Fundamental frequency is 7.1 MHz (green line), second harmonic at 14.2 MHz (dotted green line) are shown as vertical lines. FCC required attenuation of 43 dB (red line) and the target minimum harmonic suppression including Class E natural suppression of 5.7 dB (dotted red line).

7

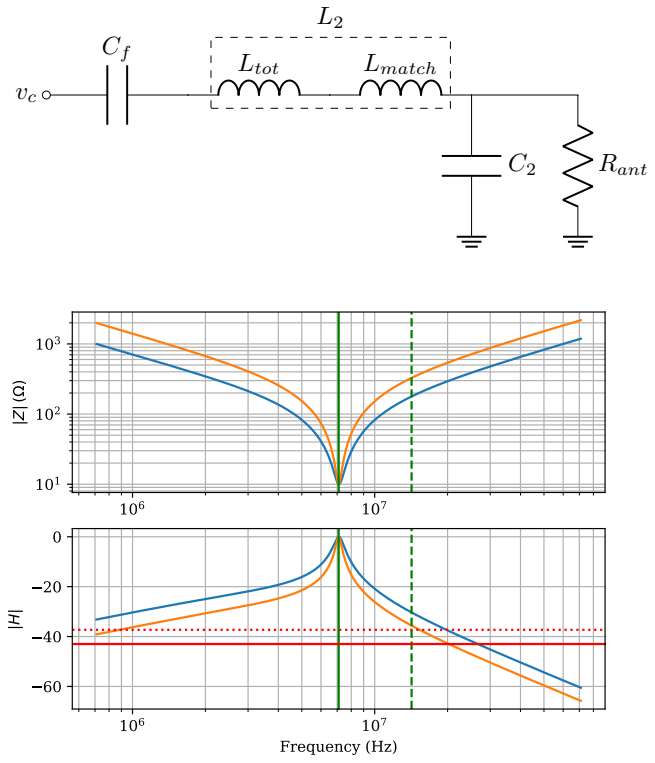
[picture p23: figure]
Ltot; Lmatch; Rant; 7 Frequency (Hz)

Figure 4: “Power Boosting” Impedance Transformer Class E with BPF. Both the transformer and BPF have the same Q: Q = 10 (blue) and Q = 20 (orange). H is normalized to 1 at ω.

2.1.1 “Power Boost” Class E

As we’ll see in Section 3, you can increase the output power by increasing VCC or decreasing the load resistance. We can use an impedance matching LC circuit to decrease the load resistance, thereby boosting power (and doing some low-pass-filtering along the way).
To increase output power and perform additional low-pass filtering, you can use an LC impedance transformer before the antenna. This lowers RL < Rant, and does not require an additional inductor since you can add the transformer inductor inductance to the existing inductor. The circuit is presented in Figure 4.
First, determine how much power out (Pout) you’d like. From there you can find C2 and Lmatch usint a standard L-match circuit:

8

RL =

0.58V

2
CC
Pout

Q =

r
Rant
RL

− 1

Lmatch =

QRL
ω

C2 =

Q

Rantω

Practically speaking, the load resistance should be at least RL > 10 Ω as to not draw too much current and avoid excessively large voltages on the filter components. Therefore, 1 < Q < 2 and Pnew < 5 × Porig. Figure 4 shows that using a L-match Q = 2, corresponding to 5× higher output power with a BPF Q = 20 gets really close to hitting the FCC requirements. However, that requires a 22 µH inductor, which is quite large. But it’s possible!

### 2.1.2 Second Order “Power Boosting” Impedance Transforming

If a simple L-network impedance transform doesn’t get enough harmonic suppression, you can further boost the Q of the low-pass filter by using a “pi” or “t” network. Circuit examples are given in Figure 5.
Both configurations are low-pass filters that can be designed to make the load appear real and smaller than Rant, thereby boosting power. The performance of the two are comparable, with T-networks having a slight edge in efficiency and Pi-networks have an edge in harmonic suppression.
The following sections shows how to calculate the values for each network.

### 2.1.3 Pi Matching

The pi network component values are calculated as follows:

1. Choose a Q that meets your bandwidth need. Lower Q means smaller inductors, and a Q = 5 seems to work pretty well.
2. Find your desired apparent load resistance using RL =

0.58V

2
CC
Pout
3. Find the value of a virtual resistance Rv that will each side of the pi-network will appear as:

Q =

r
RL
Rv

− 1 + r
Rant
Rv

− 1 ≈

r
Rv
RL

− 1

Rv ≈

Rant
(Q² + 1)

If you can use a computer to solve the un-approximated version, great -but the approximate one works OK too.

4. Find the Qs corresponding to each side of the pi-network:

Q1 =

r
RL
Rv
− 1 | Q2 =

r
Rant
Rv

− 1

9

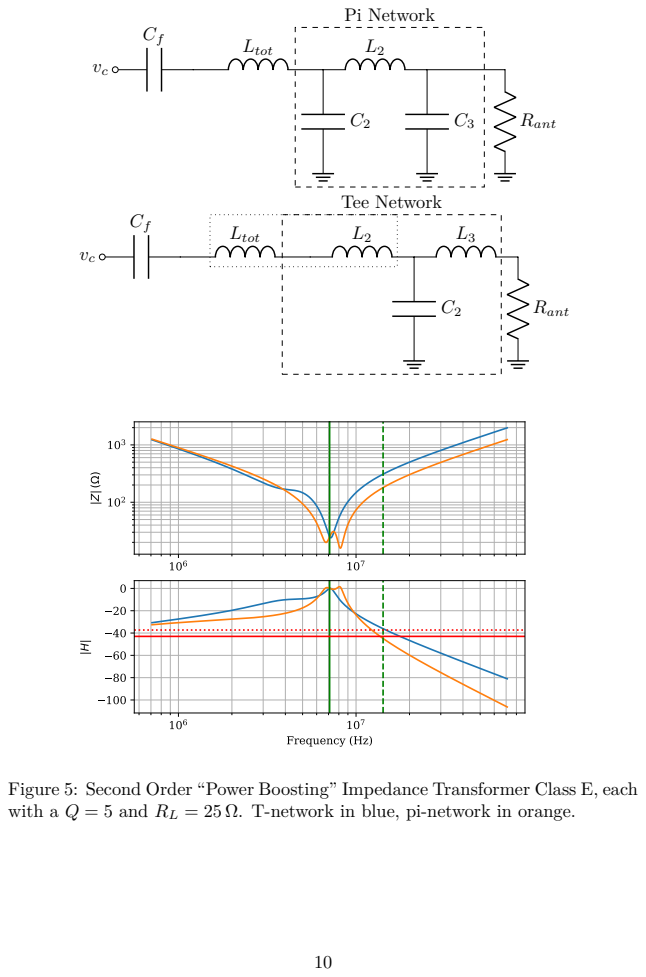
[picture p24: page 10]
Ltot; Rant; Pi Network; Tee Network; 7 Frequency (Hz)

Figure 5: Second Order “Power Boosting” Impedance Transformer Class E, each
with a Q = 5 and RL = 25 Ω. T-network in blue, pi-network in orange.

5. Find C2, C3, and L2:

C2 =

Q1
ωRL

C3 =

Q2

ωRant

L2 =

Rv
ω

(Q1 + Q2)

### 2.1.4 T-Matching

: The tee network component values are calculated as follows:

1. Choose a Q that meets your bandwidth need
2. Find your desired apparent load resistance using RL =

0.58V

2
CC
Pout
3. Find the value of a virtual resistance Rv that will each side of the t-network will appear as:

Q =

r
Rv
RL

− 1 + r
Rv

Rant

− 1 ≈

r
Rv
RL

− 1

Rv ≈ RL(Q

2 + 1)

Again, use a computer to solve this if you can, but the approximation is OK too.

4. Find the Qs corresponding to each side of the t-network:

Q1 =

r
Rv
RL
− 1 | Q2 =

r
Rv

Rant

− 1

5. Find L2, L3, and C2

L2 =

Q1RL
ω

L3 =

Q2Rant
ω
| C2 =

1
Rvω

(Q1 + Q2)

### 2.2 Pi- and T-Networks with Second Harmonic Notch Fil-

ters

To ensure that the second harmonic is properly suppressed (and impedance is zero), you can add capacitors in parallel to L2 in a pi network or parallel to L3 in a t network. This parallel LC branch can be tuned to 2 × ω to eliminate the second harmonic. This is illustrated in Figure 6. Now both typologies reach the desired harmonic suppression levels. We’ve found designs suitable for easy QRP transmitters!
Since Pi-networks seem the most promising, here’s the design equation for L2 and C4 (in Pi) or L3 and C3 (in T):

Lnew =

3
4
Lorig | C =

1
(2ω)

2Lnew

where Lorig is what the inductor would be following the standard Pi- or T-network design.
There we have it! These work great - but you still need to keep the Q > 5. Even though you are suppressing 2ω, any Q < 5 will result in having too much spurious 3ω emission.

11

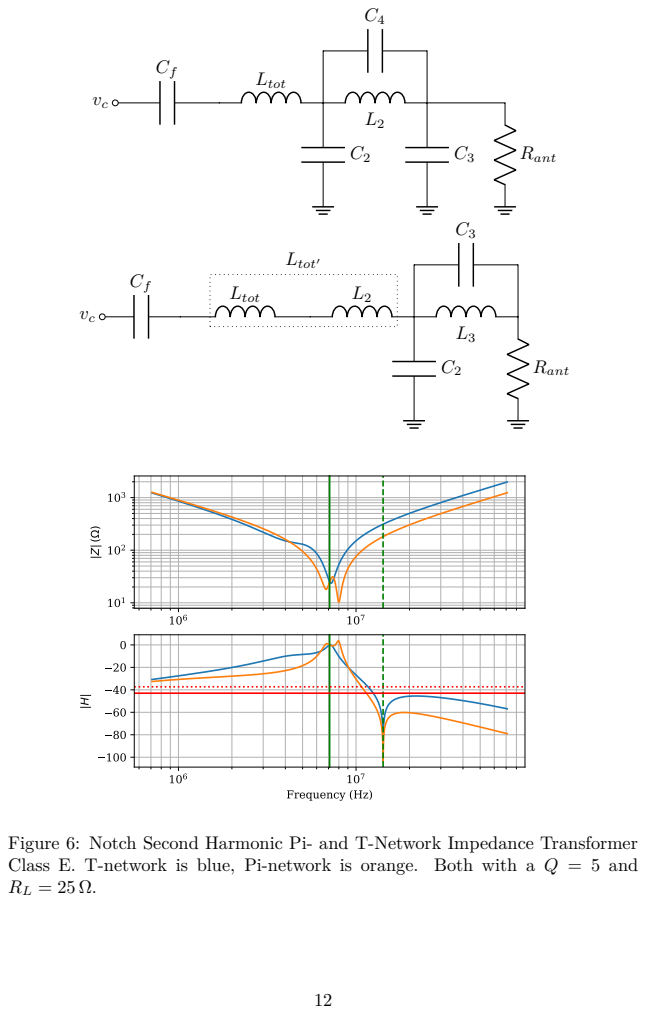
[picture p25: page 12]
Ltot; Rant; Ltot⁰; 7 Frequency (Hz)

Figure 6: Notch Second Harmonic Pi- and T-Network Impedance Transformer
Class E. T-network is blue, Pi-network is orange. Both with a Q = 5 and

Rant; 7 Frequency (Hz)

Figure 7: QCX Completely-Real LPF Class E

### 2.3 QCX Class E

Finally we arrive at the QCX Class E. This actually is a completely different design and derivation (see the other document for QCX analysis). The standard equations don’t hold because this entire design is based on not needing extra inductance to impedance match to Rant, thereby simplifying the design since you can use off-the-shelf, well-known, broadband (low Q), completely real impedance matching filters. In fact, adding extra inductance (as required in “normal” class E amplifiers) will hurt QCX Class E performance. The schematic is presented in Figure 7.

## 3 Traditional Class E Amplifiers

All Class E amplifiers generally have the same structure (with a few exceptions), shown in 8. The basic structure consists of:

- A MOSFET is switched on and off by a pulsed voltage source applied to its gate. The fluctuating switch causes the voltage vc to fluctuate, and

13

VCC; iload; Filter

Figure 8: Generic Class E Amplifier

current to flow through il

, ic, and iload.

– When the switch is closed: current flows through it and and voltage at the node connected the filter, L1, C1, and transistor drain is grounded (i.e., vc = 0).

– When the switch is open: no current flows through the transistor should be close to zero (it = 0)

- A filter is placed such that Vr is purely a single harmonic. The FCC requires 43 dB suppression of higher harmonics.

That’s it! Everything then becomes a trade off between choosing values for the different components and designing a filter so the whole system can work together. Ideally, Class E amplifiers are 100% efficient since the only places where current flows across a power dissipating element is the load resistor (antenna). While parasitic capacitances, inductances, and real resistances in all components make ideal efficiency impossible, achieving > 90% efficiency is common.
Here are the traditional steps to analyze the circuit and derive component values:
1. Start by saying we’ll make L1 really large (much larger than the inductance of the load), thus making it an RF choke that lets DC pass through but blocks all AC signals. Therefore il = IDC
2. Next, we say that the filter only allows frequency ω = 2πf to pass through it, it’s a perfect band pass filter that essentially has zero impedance at ω and infinite impedance at all harmonics and DC. Therefore we can write iload = a sin(ωt) + b cos(ωt).

14

3. Now that we know iload and il

, we can find the current in the switching capacitor branch which is simply is = IDC − a sin(ωt) − b cos(ωt).

4. Using is, we can find the voltage across the capacitor. We’ll say the switch is closed from time t = 0 to πω, and the switch is opened from t = π/ω to 2π/ω. Therefore:

t = 0 → π/ω : vc = 0

t = π/ω → 2π/ω : vc =

1
C1

Z t

π/ω

ic dt⁰ =

1
C1

Z t

π/ω

is dt⁰

=

1
C1

Z t

π/ω

IDC − a sin(ωt⁰

) − b cos(ωt⁰

) dt⁰

=

1
ωC1

[IDC (ωt − π) + a cos(ωt) + a − b sin(ωt)]

We know the switch is closed at ωt = 2π, so the voltage should be zero then. Therefore:

0 =

1
ωC1

[πIDC + 2a]

a = −

π
2

IDC

We also can say we want the first derivative of the voltage to be zero when the switch is first closed for maximum efficiency.

dvc
dt
t=2π/ω

= 0 =

1
C1

h
IDC +

π
2

IDC sin(ωt) − b cos(ωt)

i
t=2π/ω
b = IDC

Therefore:

t = 0 → π/ω : | vc = 0
t = π/ω → 2π/ω : | vc = IDC ωC1

ωt −
3π
2
−

π
2

cos(ωt) − sin(ωt)

and

iload = IDC
−

π
2

sin(ωt) + cos(ωt)

≈ IDC √ π
2 + 4
2

cos (ωt − 57.5

◦
)

!

We can plot vc and see that the voltage is zero when the switch is closed (first half of the period the capacitor in grounded), then it increases and returns to zero right before the switch closes again in Figure 9. We can now also plot what current is is doing through the cycle in Figure 10.

15

Time (2π/ω); vc/VCC

Figure 9: Capacitor voltage versus time for one switch period.

5. We’ve had IDC hanging around for a while, but we don’t really know what it is. To find it, we can realize that the power in to the circuit only comes fro VCC , and the power is only dissipated in RL, therefore those two powers must be equal.

P = VCC IDC =

1
2

|iload|

2RL =

4 + π

2
8

I

2
DC RL

IDC =

8
4 + π

2

VCC
RL

P =

8
4 + π

2

V

2
CC
RL

The conclusion here is the you can increase output power by either increasing supply voltage, or by using an impedance transforming network to reduce an antenna’s load from 50 Ω to something less (usually around 10 Ω)

6. Now we know all the currents in the circuits at all time and the voltage across the capacitor, inductor, transistor drain to source, and presented to the filter. The last step is to figure out what filter we need to both remove unwanted frequency components and impedance matching to our load.

We know the voltage vc and the current iload, so our filter just is something with the impedance Zf ilt =

vc
iload

. We know iload = 0 for all frequencies except the harmonic, therefore Zf ilt(ω) = ∞ for all frequencies except

16

Time (2π/ω); it/IDC
Time (2π/ω); ic/IDC

Figure 10: Transistor source current (top) and capacitor current (bottom) over one switch period.

17 the one we want. This is a crucial part of Class E design. Sometimes people think the filter is only there to filter out frequencies from reaching the antenna when in fact it is there to stop those currents from even flowing out of the input node in the first place!

Now that we know what we want in the frequency domain, we can look at what vc looks like in the frequency domain by representing vc as the sum of sine and cosine functions (write it as a “Fourier Series”).

vc =

8
4 + π

2

VCC
ωC1RL

1
π

−

1
2

sin(ωt) −

π

2 − 8
4π

cos(ωt)

+

1
6

sin(2ωt) −

2
3π

cos(2ωt) + 2
9π

cos(3ωt) + · · ·

and as a reminder

iload =

8
4 + π

2

VCC
RL
−

π
2

sin(ωt) + cos(ωt)

So the filter design begins to pop up out:

- We need a DC blocking capacitor since there is a DC component in vc and none in iload.
- We’d want an infinite impedance at 2ωt. Interestingly, the voltage is already smaller than the fundamental by a factor of:

|vc(2ω)|
|vc(ω)|

=

q
1/62
+

2
3π

2
q
1/22
+

π²−8
4π

2

≈ 0.52 ≈ −5.7 dB

hich is exactly what Cripes (NM0S) saw when he experimentally measured and designed his Class E with second harmonic notch filter. Now that we know what we want for the higher harmonics, we can turn our attention to the fundamental frequency ω:

vc =

8
4 + π

2

VCC
ωC1RL
−

1
2

sin(ωt) −

π

2 − 8
4π

cos(ωt)

iload =

8
4 + π

2

VCC
RL
−

π
2

sin(ωt) + cos(ωt)

It turns out that if our filter acts like an inductor in series with our load resistor RL (representing our antenna), we can get vc and ir to “line up” with each other so that we can get ideal, perfect matching and theoretically achieve 100% efficiency! This is seen in Figure 11.

We can then find what ∆L needs to be.

18

vc
iload

Perfect BPF
∆L

RL

+

−

vr

Figure 11: Traditional impedance matching for a Class E Amplifier

vc = ω∆L

diload
dt + iloadRL

=

8
4 + π

2

VCC RL | −ω∆L −
RLπ
2

sin(ωt) +
−

ω∆Lπ
2

+ RL

cos(ωt)

vc =

8
4 + π

2

VCC
ωC1RL
−

1
2

sin(ωt) −

π

2 − 8
4π

cos(ωt)

Set those bottom two lines equal to each other and you’ll find expressions for ∆L and C1.

∆L =

π(π

2 − 4)RL
16ω

≈

1.1525RL
ω

C1 =

1
ωRL

8
π(4 + π

2)

≈

1
5.4466ωRL

Which also gives us an even simpler expression for vc.

vc = 0 | t = 0 → π/ω
vc = πVCC ωt −
3π
2
−

π
2

cos(ωt) − sin(ωt)

| t = π/ω → 2π/ω

vc = VCC
1 −

π
2

sin(ωt) −

π

2 − 8
4
cos(ωt) | Fourier Series

+

π
6

sin(2ωt) −

2
3

cos(2ωt) + 2
9

cos(3ωt) + · · ·

It’s important to note that C1 can be reduced to compensate for the output capacitance of the MOSFET. C1 can be reduced by the output

19 capacitance of the MOSFET (COSS) when the MOSFET “switch” is open and Vds ≈ 2 × VCC on average. According to the BS170 datasheet, for example that’s about 20 pF if VCC = 12 V. This is especially important if you have multiple transistors in parallel (for decreased power dissipation from decreasing the resistance through the “switch” as well as sharing the heat load). It’s good to experimentally tweak C1 a little bit to see if you can squeeze and extra efficiency out.

7. Next we can revist “how big does L1 need to be?” We just said it has to be big - how big? Basically we want the current through L1 ≈ IDC , which means we want all the other frequency components to be much less than IDC . So what is the current through L1?

Basically, we know that the current through L1 is going to have a DC component and some AC. We just want the DC component to be much larger than the AC. So let’s calculate the current through L1!

il =

1
L1

Z
VCC − vc dt

=

1
L1

Z
VCC − VCC
1 −

π
2

sin(ωt) −

π

2 − 8
4

cos(ωt)

+

π
6

sin(2ωt) −

2
3

cos(2ωt) + 2
9

cos(3ωt) + · · ·
dt

= IDC +

VCC
ωL1
−

π
2

cos(ωt) + π

2 − 8
4

sin(ωt)

+

π
12

cos(2ωt) + 1
3

sin(2ωt) + 2
27

sin(3ωt) − · · ·

So we want L1 to be large enough such that the magnitude of the largest AC components of iL is much less than IDC . By inspection, the ω component (fundamental frequency) is the largest, therefore

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
2 − 8
4

2

8
4 + π

2

VCC
RL

VCC
ωL1

√
π

4 − 12π

2 + 64
4

VCC
1.73RL

1.64VCC
ωL1
L1 2.84RL
ω
8. Finally, we can choose the filter. We want a filter with infinite impedance at all frequencies except at our chosen frequency. An inductor and capacitor in series does that, as shown in Figure 12.

20

vc

Cf

iload

Lf | ∆L

RL

+

−

vr

Ltot

Figure 12: Traditional filter with impedance matching for a Class E Amplifier

Theoretically, you want a perfect filter with infinitesimal bandwidth (∆ω). The ratio of a filter’s frequency to its bandwidth is a filter’s Q =

ω
∆ω

, so
you’d like an infinite Q. For a given Q, you can therefore find Cf and Lf in Figure 12:

Qf =

ωLf
RL

Lf =

QfRL
ω

Cf =

1
ω²Lf

=

1
QfRLω

Ltot = Lf + ∆L =

RL
ω

(Qf + 1.1525)

Although we want Qf = ∞, this whole approach works well for Qf > 10 or so. In fact, if you use a Q ≈ 20, you can achieve 30 dB suppression with just that single inductor! However, tuning that LC circuit will be tricky, experimentally. For lower Qf , check out Sokal’s QEX for equations to “correct” for imperfect Qf .

2

2As a note, that paper decreases capacitance rather than increases inductance which has the same effect. Also, they use QL instead of Qf , which includes the extra impedance matching.

21

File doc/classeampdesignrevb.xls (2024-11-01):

Class E Power Amp Design Using NMØS Equations Presented at FDIM 2009
 |  |  |  |  |  |  | Use print button on toolbar to print your design's values.
Enter the following
Band in Mc |  | 7.1
Desired Output Pwr |  | 5
Power Supply Voltage |  | 12
Mosfet Type |  | IRF510 |  |  |  |  |  |  |  |  | Intermediate Calcs for L2
Rdson Ω |  | 0.54 |  |  |  |  |  |  |  |  | 30.39683237
Coss pF |  | 81 |  |  |  |  |  |  |  |  | 0.6817267509
Calculations
Load Resistance Ω |  | 8
C1 pF * |  | 452
Choose C2 pF ** |  | 1402
L2 uH |  | 0.68
C3 pF |  | 1121
C5 pF |  | 1121
L3 uH |  | 0.34
C4 pF |  | 374
Choose L1 uH *** |  | 10.23
* Must be mounted vy close to the MOSFET. Directly bridge the drain and source if possible
** Reactance of C2 must be 1 - 2 x load resistance R ... C for 2RXc is calculated for you
*** Must be >10 x L2 ... 15 x L2 is calculated for you
Data (typical) for popular MOSFETS for QRP Pwr Amps |  |  |  |  |  | Capacitors: Use NP0, C0G, or Silver Mica
 | 2N7000 | BS170 | IRF510 | IRF520 | STP16NF06 | Recommended Toroid Cores: T50-6 or T50-7
Voltage | 60 | 60 | 100 | 100 | 60 | Get toroid calculator here: |  | http://www.kitsandparts.com/tcalc.html
Id | 200ma | 500 | 5.6A | 9.2 | 16 | Reference and recommended reading:
Rdson Ω | 1.2 | 1.2 | 0.54 | 0.25 | 0.08 | Cripe, David, NMØS, "Class E Power Amplifiers for QRP"
Coss * pF | 11 | 17 | 81 | 130 | 70 | QRP Quarterly Vol 50 Number 3 Summer 2009, pp 32-37
Pwr Out W | 1 to 1.5 | 1 to 2 | 2 to 10 | 2 to 20 | 2 to 20 | Errata: Volume 50 Number 4 Fall 2009 p4
Case | TO-92 | TO-92 | TO-220 | TO-220 | TO-220
*Output capacitance i.e. Drain to Source Capacitance |  |  |  |  |  |  | Spreadsheet by | WAØITP
Can be paralleled for more output. Calculate the parallel Coss and Rdson |  |  |  |  |  |  |  | Design Formulas and Specs by | NMØS | 2010-09-17
 |  | Cell D12 should be:Âtimes, serif; BACKGROUND-COLOR: #fff">Cell D12 should be:Â =ROUND((0.32*D7*D7)/D6-1.5*D9,0)
 |  |  | 8

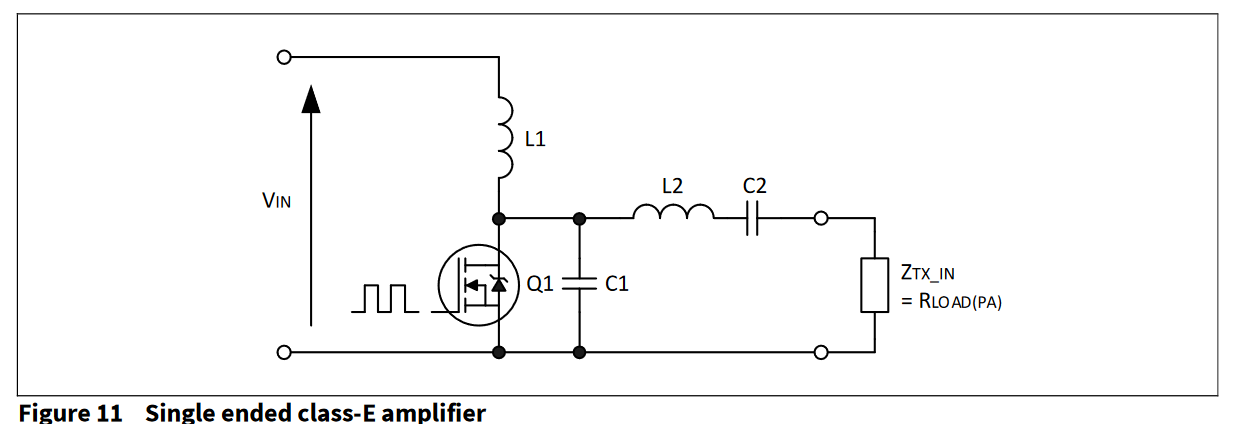
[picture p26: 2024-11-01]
images/principle_schematic_class_E.png

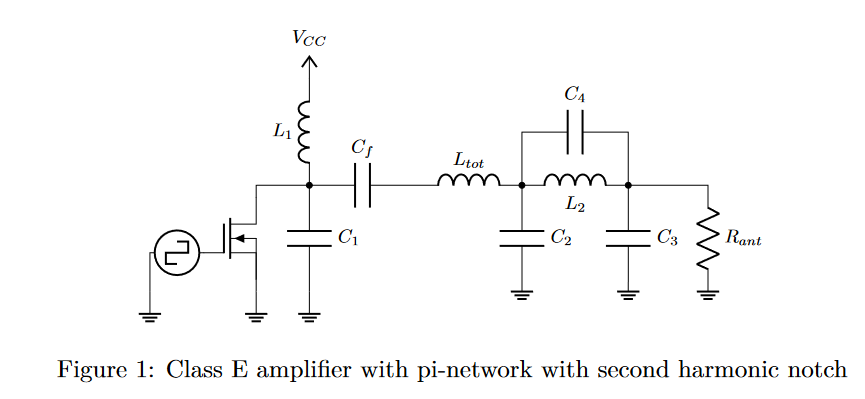
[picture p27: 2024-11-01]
images/class_e_pi_filter.png

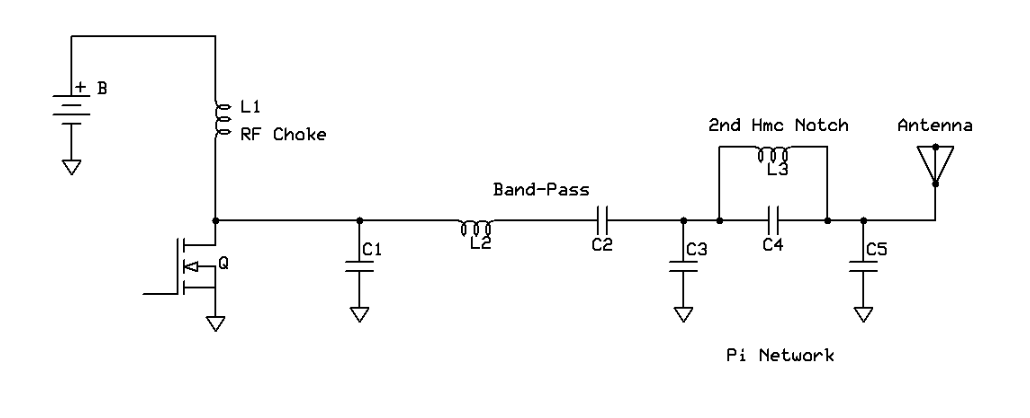
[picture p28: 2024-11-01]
images/NM0S_Class-E.png

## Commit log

2024-11-01 Add more documentation
    [classeampdesignrevb.xls]
2024-11-02 Finalize circuit design choice
2024-11-03 Selecting critical circuit components
2024-11-08 Add temperature protection simulation
2024-11-11 Add audio filter design
2024-11-20 Reduce offset from voltage reference
2024-12-12 First version of the schematic
    [AMT5000-24.PcbDoc, AMT5000-24.PrjPcb, Interface.SchDoc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]
2024-12-21 Moving oscillator to separate module
    [AMT5000-24.PrjPcb, AMT5000-24_Oscillator.PrjPcb, AMT5024-Oscillator.PrjPcb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]
2024-12-24 Replace right angle wire-to-board connector by straight ones
    [AMTOSC.PcbDoc, Modulator.SchDoc, Oscillator.SchDoc]
2025-01-01 Audio amplifier design ready for generating production data
    [AMT5000-24_Audio_Amplifier.PrjPcb, Modulator.SchDoc, PCB.PcbDoc]
2025-01-01 Replace order codes because of availability problem
    [Modulator.SchDoc]
2025-01-01 Correct TVS part code
    [AMT5000-24_Audio_Amplifier.PrjPcb, Modulator.SchDoc]
2025-01-01 Update U.FL connectors
    [AMT5000-24_Oscillator.PrjPcb, AMTOSC.PcbDoc, Oscillator.SchDoc]
2025-01-01 Obfuscating BoM
2025-01-01 Fitting it all on one sheet
    [AMT5000-24.PrjPcb, Interface.SchDoc]
2025-01-01 Removing oscillator and audio amplifier
    [AMT5000-24_RF_Amplifier.PrjPcb, main.SchDoc, transmitter.SchDoc]
2025-01-01 Finish schematics
    [transmitter.SchDoc]
2025-01-08 AMTAMP 1.0.0A ready for generating gerber
    [AMT5000-24_RF_Amplifier.PrjPcb, transmitter.SchDoc]
2025-06-02 Add resistive divider on oscillator output
    [AMT5000-24_Oscillator.PrjPcb, AMTOSC.PcbDoc, Oscillator.SchDoc]
2025-06-02 Hide refdes
    [AMTOSC.PcbDoc]
